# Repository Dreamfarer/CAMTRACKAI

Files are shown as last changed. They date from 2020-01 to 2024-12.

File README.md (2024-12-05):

# CamTrackAI

This is our project work for school. It is an autonomous device powered by a Raspberry Pi 4 that rotates a camera according to object tracker data by OpenCV.

It uses the TCP/IP to send a video source from the Raspberry Pi to a more powerful computer to calculates the object tracking. It will return the calculated data to the Raspberry Pi which then communicates with our Dynamixel Rx-64 motors.

## Prerequisites

You will need these following utilities/devices:

* [Dynamixel Rx-64](http://www.robotis.us/dynamixel-rx-64-hn05-n101/) (x2) - These are the motors we used. But you can use any Robotis Dynamixel motor.
* [Robotis USB2Dynamixel Adapter](https://www.trossenrobotics.com/robotis-bioloid-usb2dynamixel.aspx) - It is used to communicate with the Dynamixel motors.
* [Raspberry Pi Camera Module](https://projects.raspberrypi.org/en/projects/getting-started-with-picamera) - Our camera, the Pi Cam. But any webcam will work fine.
* [Raspberry Pi 4 Model B](https://www.pishop.us/product/raspberry-pi-4-model-b-4gb/) - The computer we used as server. But you can use any computer with any Linux distro.
* [Gens Ace 5000mah 14.8V](https://www.gensace.de/gens-ace-5000mah-14-8v-45c-4s1p-flat-lipo-battery.html) - You will need a 4S1P Battery to power the motors. Additionally add a 3A step down to 5V to power the Raspberry Pi.

You will need the following libraries/packages to compile this code:

* [OpenCV](https://opencv.org/releases/) (Not included, installing instructions further down) - For the tracking algorithm
* [Dynamixel SDK](https://github.com/ROBOTIS-GIT/DynamixelSDK) (Necessary parts included) - For controlling the Dynamxiel motors
* [FLTK](https://www.fltk.org/software.php) (Not included, installing instructions further down) - GUI
* [Avahi-Daemon](https://linux.die.net/man/8/avahi-daemon) (Not included, installing instructions further down) - Used for mDNS to resolve an IP address by a hostname.

## Installing

### OpenCV installation

Follow the tutorial found [here](https://linuxize.com/post/how-to-install-opencv-on-ubuntu-18-04/). There are two ways presented to install OpenCV. Choose the second way found further down.

After you finished the setup, type a final command into the console.

```
$sudo apt-get install libopencv-dev
```

### FLTK (The Fast Light Tool Kit ) installation

Follow these steps to a successful installation of FLTK. The complete tutorial is to be found [here](https://courses.cs.washington.edu/courses/cse557/14au/tools/fltk_install.html)

Firstly, you will need to download FLTK and extract it. Then follow these steps:

```
$./configure
$make
$sudo make install
```

### Dynamixel SDK installation

We need to load the appropriate Dynamixel library. In the server's makefile, search for:

```
dxl_sbc_cpp
```

and change it to the appropriate library found in '/YOUR/PATH/TO/CAMTRACKAI/DynamixelSDK/build'. If you have a x64 system, change the makefile to:

```
dxl_x64_cpp
```

Note that the suffix '.so' and the prefix 'lib' are missing. Also note that you have to install the library. You can do this by the following:

```
$cd /YOUR/PATH/TO/CAMTRACKAI/DynamixelSDK/build/linux64
$make
sudo make install
```
### Avahi Daemon installation

```
$sudo apt-get install avahi-daemon
```

### Change path

Open both makefiles and find this variable:

```
CAMTRACKAI_PATH = /home/theb3arybear/Desktop/CamTrackAI/GitHub/CamTrackAI
```

Change the path to your location.

```
CAMTRACKAI_PATH = /YOUR/PATH/TO/CAMTRACKAI
```

### Change motor ID

Navigate to in CamTrackAIServer.cpp in Server and find these line:

```
#define DXL_ID_1        1
#define DXL_ID_2        2
```

Change the ID of the motors to match yours. 

```
#define DXL_ID          X
```

### Change resolution

Navigate to CamTrackAIClient.cpp in Client and find these lines:

```
#define SCREEN_X        1920
#define SCREEN_Y        1080
```

Change them to match your monitor. You can run 'xdpyinfo | grep dimensions' if you need to know them.

### Networking Setup

Because this application uses mDNS, you can set up your network how would like it to be. The easiest setup would be connecting the server and the client with an ethernet cable. It is important to match the subnet mask and the IP addresses of both computers. To change the IP address and the subnet mask, type the following to the command line (This is an example, you can choose the addresses freely):

```
$sudo ifconfig eth0 192.168.1.1 netmask 255.255.255.0
```

## Compile and Run

Open the console and move to the makefile's location. First:

```
$make
```

Run the following command (on Raspberry Pi) to start the server:

```
$./CamTrackAIServer
```
Then run the next command (on external Computer) to start the client:

```
$./CamTrackAICLient
```

## Further information

To completely remove OpenCV, type the following line into console:

```
$find . -type d -name "*opencv*" -prune -exec rm -rf {} \;
```

## Known Issues (Unsolved)

* There are issues communicating with more than one Dynamixel motor. For unknown reason you cannot talk to two motors shortly after each other. There must be a short pause.
* After some time it may well be that the program stops for unknown reason.

## Authors

* **Dreamfarer** - *Project Planning/Coding/GitHub/Documentation*
* **Kay** - *Project Planning/Planning and building of construction/Documentation*
* **Luca** - *Project Planning/Documentation*

* **Jeremy Morgan** - *Provided code for reading output of a console command (getStdoutFromCommandFunc function in client.cpp)* - [Found Here](https://www.jeremymorgan.com/tutorials/c-programming/how-to-capture-the-output-of-a-linux-command-in-c/)
* **Steve Tuenkam** - *Provided idea behind sending video over TCP/IP using OpenCV* - [Found Here](https://gist.github.com/Tryptich/2a15909e384b582c51b5)

## Thanks to

Linus Torvalds for creating the best kernel, the guys over Parrot OS for the best Linux distro, the whole stackoverflow community for providing ideas and saving programmers' lives.

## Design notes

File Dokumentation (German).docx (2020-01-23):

Eine Projektarbeit von: Luca Gloor G3A, Gianluca Imbiscuso G3A und Kay Obermeier G3A Unter Betreuung von Martin Stangl

22.1.2020

Dokumentation

Zum Bau eines autonomen, objektverfolgenden Bilderkennungs- und Kamerasystems mithilfe einer Künstlichen Intelligenz.

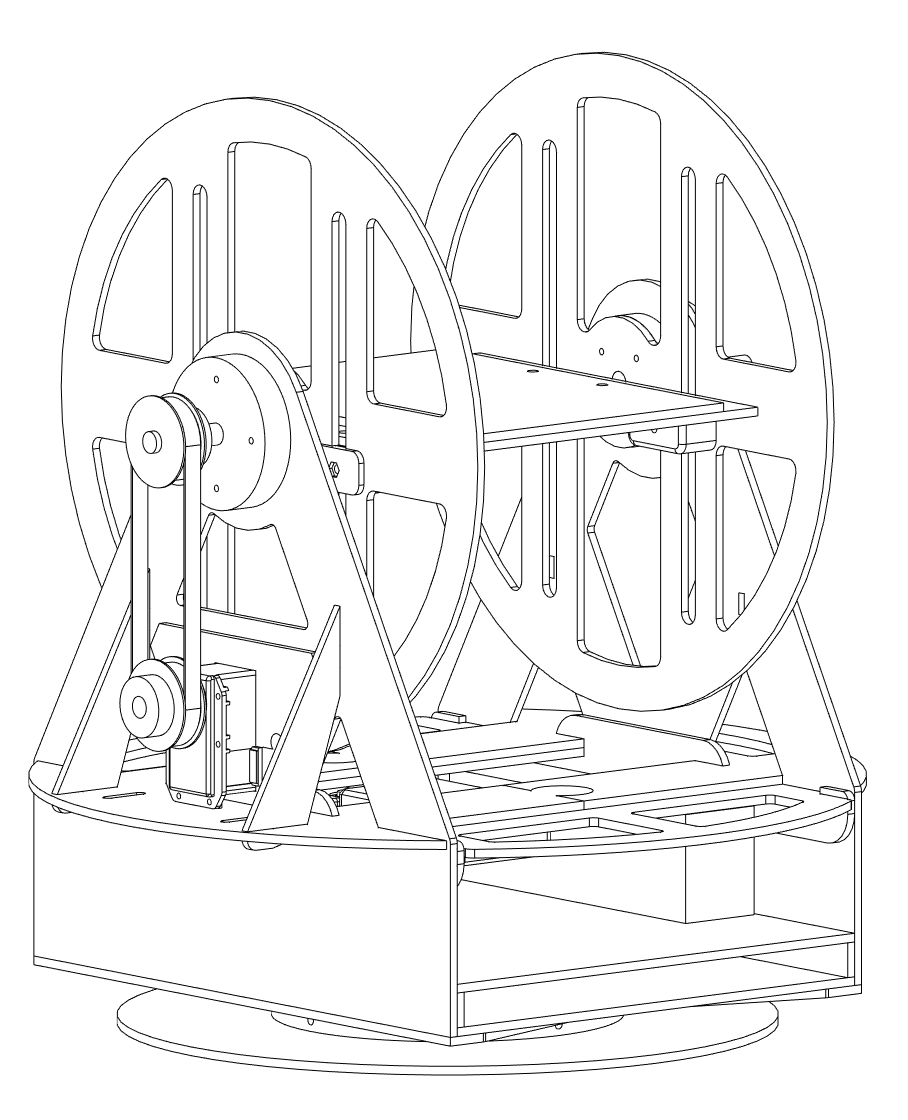
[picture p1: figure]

# Abstract

Diese Projektarbeit befasst sich mit der Entwicklung und der Konstruktion eines autonomen Kamerasystems. Dieses soll in der Lage sein, vom Benutzer ausgewählte Objekte automatisch zu erkennen und zu verfolgen. Das System soll sich in X-, und Z-Richtung drehen können. Gesteuert wird die Konstruktion hierbei mithilfe einer Künstlichen Intelligenz. Um den Aufwand zu verringern, wird die KI eines Open-Source-Projektes verwendet und für unsere Zwecke angepasst.

Die gesamte Arbeit haben wir in einen Konstruktions- und einen Programmier-Teil gegliedert. Das ermöglichte uns, gleichzeitig und unabhängig voneinander bereits an der Konstruktion sowie am Programm zu arbeiten.

Mit unseren Ergebnissen sind wir zufrieden. Natürlich gibt es noch hunderte Dinge, die man an diesem Projekt weiterführen, verfeinern oder neu hinzufügen könnte.

# Vorwort

Wir sind an einer Flugshow auf diese Idee gestossen. Da es sehr anstrengend ist einen gesamten Nachmittag die Kamera zu halten, kamen wir auf die Idee ein Gerät zu bauen. Da zu diesem Zeitpunkt gerade die Projektarbeit bevorstand, entschieden wir uns dieses Projekt zu verwirklichen.

Wir wollen uns hiermit bei allen Personen bedanken, die uns bei der Arbeit unterstützt haben.

Besonderer Dank geht an Andreas Obermeier der für uns den Raspberry Pi, die Pi Cam, die Dynamixel Motoren, die Zahnriemen, Wellen- und Axiallager sowie das Holz zur Verfügung stellte. Auch für die stetige Hilfsbereitschaft für Tipps und Vorschläge sind wir sehr dankbar.

Ebenso danken wir auch unserer Betreuungsperson Martin Stangl für den reibungslosen Start in unser Projekt.

# Inhaltsverzeichnis

# 1. Einleitung

Autonomes Objekttracking ist an sich keine neue Idee. Oftmals werden aber die zu trackenden Objekte speziell markiert, damit ein Gerät diese leicht erkennen kann. Bei unserer Arbeit haben wir eine Künstliche Intelligenz angewendet, die das Objekt anhand seiner Form erkennt und somit die Motoren ansteuern kann. Solche Systeme sind auch heutzutage bereits existent, nur findet man solche Systeme nur in der Rüstungsindustrie. Wir versuchen eine «Low-Budget» Variante in Marke Eigenbau nachzubauen.

## 1.1 Hauptziel

Das Hauptziel der Arbeit ist der Bau eines Drehturmes, welcher eine Kamera um die eigene X-Achse, wie auch die Z-Achse drehen kann. Da dieser autonom angesteuert werden soll, wurde die Verwirklichung des Projektes in 2 Teile aufgeteilt: Die Konstruktion des Drehturmes und die Einbettung der Künstlichen Intelligenz für die Ansteuerung der Motoren, die den Turm bewegen.

## 1.2 Eigene Zusatzkriterien

### Universell brauchbare Plattform für den Gebrauch verschiedener Kameratypen

Das Ziel dieses Kriteriums ist es, dass nicht nur wir, sondern auch andere Menschen mit anderen Kameras das Kamerasystem verwenden können. Auch mit unterschiedlich grossen Objektiven soll der Drehturm nicht aus dem Gleichgewicht gebracht werden.

### Benutzerfreundliche Bedienungsoberfläche (GUI)

Damit das Kamerasystem von anderen Menschen benutzt werden kann, ist wichtig, dass die Bedienung auf den ersten Blick klar erscheint. Der Benutzer soll das Produkt einfach und ohne zu raten bedienen können.

### Sauberer und übersichtlicher Code

Das Projekt soll nicht einfach funktionieren, sondern auch nachvollziehbar sein. Da alles durch ein Programm gesteuert wird, ist das Ziel dieses Kriteriums, dass dessen Code sauber geschrieben, kommentiert und übersichtlich gestaltet ist.

# 2. Theoretische Grundlagen

## 2.2 Künstliche Intelligenz

«Künstliche Intelligenz ist ein Teilgebiet der Informatik, welches sich mit der Automatisierung befasst. Der Begriff ist nicht eindeutig, weil eine genaue Definition fehlt.

Ist ein Computerprogramm intelligent, wenn es jedes Sudoku lösen, oder die besten menschlichen Spieler im Schach schlagen kann? Es stellt sich heraus, dass die AI-Komponente für viele komplizierte Probleme schlicht in besonders schlauen und effizienten algorithmischen Lösungen oder Abschätzungen besteht. Solch klassische Herangehensweisen werden oft mit der Abkürzung GOFAI (good oldfashioned AI) bezeichnet. Sie erfordern, dass der Programmierer, aufgrund seiner Intelligenz, einen Lösungsweg für das gegebenen Problem entwickelt und diesen in Programmcode umsetzt.» (Oinf.ch, Künstliche Intelligenz)

GOFAI ist ja schön und gut, doch wirklich intelligent ist das noch nicht. Immer wichtiger wird daher maschinelles Lernen, bei dem der Mensch keinen Lösungsalgorithmus vorgibt. Es basiert viel mehr auf dem Prinzip von Trial und Error. Vorgegeben werden der KI hierbei nur die Eingabe-Daten, ein neuronales Netz und ein Endergebnis. Das neuronale Netz besteht aus mehreren Schichten von Knoten, die miteinander verbunden sind. Je nach Eingabewert werden die Daten im neuronalen Netz verarbeitet und ausgegeben. Wenn das Endergebnis stimmt, werden, auf Basis dieser Generation, kleine Veränderungen in den Verbindungen gemacht, die den Prozess verfeinern. Ebenso wenn das Endergebnis falsch ist. Dann sind die Anpassungen dementsprechend höher und können in eine ganz andere Richtung gehen. So lernt die KI, wo und wie sie sich verbessern kann. Genauso wie wir immer besser werden, wenn wir etwas viel üben oder repetieren, verbessert sich auch die KI entsprechend der Repetitionen, die es macht. Je länger eine KI trainieren kann, desto besser wird sie.

### OpenCV

OpenCV (Open Computer Vision) ist die wohl bekannteste Open Source Bibliothek mit grösstenteils Algorithmen für Echtzeit-Bildverarbeitung. Sie kann auf allen herkömmlichen Betriebssystemen wie Linux, Windows oder Mac OSX kompiliert und verwendet werden. Geschrieben ist die Bibliothek in C/C++, doch sie unterstützt unter anderem auch Python und Java.

### Tracker Algorithmen

Das Ziel des «Object Trackings» ist es, Objekte über viele Bilder hinweg zu verfolgen. Der Tracker generiert ein Aussehens-Modell des ausgewählten Objekts. Hinzu wird ein Bewegungsmodell kreiert. Dieses misst die Geschwindigkeit und die Richtung über mehrere Bilder hinweg und kann so voraussehen, wo das Objekt sein wird. In diesem Bereich sucht der Tracker dann nach einem Objekt, das dem Aussehens-Modell gleicht. Es wird zwischen «Online» und «Offline» unterschieden. «Online» bedeutet, dass der Tracker ein Aussehens-Modell berechnet, während das Programm läuft. Es passt das Modell den Umständen an. «Offline» bedeutet, dass bevor das Programm gestartet wird, der Tracker schon weiss, wie das Aussehens-Modell aussieht. Solche Tracker werden zum Beispiel genutzt, um Gesichter zu erkennen. Diese Tracker sind viel schneller und in ihrer trainierten Disziplin sehr gut, doch können nur diese spezifischen Objekte verfolgen.

## 2.3 Motoren

### Schrittmotoren

Schrittmotoren sind in der Robotik immer anzutreffende Motoren. Durch ihre Einfachheit und hohen Präzision eignen Sie sich stark für solche Projekte. Auch sind sie sehr preisgünstig und Energieeffizienz. Jedoch haben Schrittmotoren wegen ihrer hohen Präzision im Vergleich zu anderen Motoren ein tiefes Drehmoment.

### Dynamixel Motoren

Dynamixel Motoren sind professionelle Motoren für die Robotik. Sie sind sozusagen die Königsklasse was Motoren betrifft. Durch ihre kompakte Grösse haben sie im Vergleich zu anderen Motoren ein enorm hohes Drehmoment. Ebenfalls lassen sich diese Motoren in Serie schalten, welches die Kabelführung bei Robotern extrem vereinfacht. Durch Ihre hohe Leistung, Qualität und Anwendungsmöglichkeiten fallen solche Motoren oft sehr teuer aus. Speziell bei diesen Motoren ist eine kompliziertere Ansteuerung. Um die Motoren über eine USB-Schnittstelle anzusteuern, braucht man einen Dongle. Für Dynamixel Motoren heisst dieser USB2Dynamixel.

## 2.4 Raspberry Pi

Ein Raspberry Pi ist ein kompakter Computer, nicht viel grösser als ein DIN A7 Papier. Er eignet sich wunderbar als Rechner für selbstgebaute Geräte. Durch seine Einfachheit und Modularität findet man einen Raspberry Pi in allen möglichen Schulprojekten. Ebenfalls ist dieser Computer sehr preisgünstig und vergleichsweise leistungsstark.

## 2.5 FLTK Fast Light Toolkit

FLTK ist eine auf C++ basierende GUI (General User Interface), die auf allen herkömmlichen Betreibsystemen wie Linux, Mac OSX und Windows funktioniert. Sie ist klein, schnell, portabel, benutzerfreundlich und braucht wenige Ressourcen. Das hauseigene Programm FLUID kann benutzt werden, um eine GUI aufzubauen.

## 2.6 Makefile

Ein wichtiger Teil des Kompilierens sind sogenannte Makefiles. Makefiles sind Linux-spezifische Dateien, in denen Parameter für den Kompilierer hineingeschrieben werden. Dies erleichtert das Kompilieren. Man schreibt einfach «$make» in den Terminal und das ganze Projekt wird kompiliert.

## 2.7 TCP/IP

TCP/IP ist eine Protokoll-Familie, welche genutzt wird, um mit anderen Computern über ein Netzwerk zu kommunizieren. Das TCP (Transmission Control Protocol) nimmt Daten von Anwendungen an und teilt sie in Pakete auf. Diese übergibt es dann dem IP (Internet Protocol). Dieses Protokoll sorgt dafür, dass die Pakete vom TCP adressiert und über das Netzwerk gesendet werden.

## 2.8 mDNS

Das Konzept des mDNS (Multicast DNS) löst Hostnamen zu IP Adressen auf und folgt dem herkömmlichen Prinzip des DNS. Dies hat jedoch einen Haken, denn es muss ein DNS Server im Netzwerk aufgesetzt sein. Dies ist nicht oft der Fall. Genau hier setzt mDNS an. Durch mDNS präsentiert sich der Computer im Netzwerk und sendet seine IP Adresse, wenn ein Computer seinen Namen «ruft».

# 3. Methode

## 3.1 Bau des Drehturms

### Konstruktion des Grundgerüsts

Für den Bau des Drehturms haben wir uns entschieden, das gesamte Produkt zuerst in einem CAD-Programm zu entwerfen und zu designen. Wir haben uns hierbei auf Fusion 365 geeinigt. Das CAD-Programm ist für Privatpersonen gratis zu gebrauchen. Da wir bereits in früheren, privaten Projekten dieses CAD benutzten, fiel es uns leicht mit diesem zu arbeiten.

Als Grundidee des Drehturms nahmen wir die Kameradrehtürme aus Drohnen zum Vorbild. Diese bestehen aus zwei motorisierten Achsen, eine für die Höhen- und die andere für die Seitenverstellung. Grob gesehen ist es ein Riesenrad auf einem Karussell.

Am Anfang begrenzten wir uns auf eine Grösse für die Kameras. Im Durchschnitt ist eine Fotokamera etwa 15cm breit. Damit wir genug Spielraum hatten, setzten wir unsere Breite für den Hauptlift auf 20cm. Von da aus konnten wir anfangen. Als Erstes entstand der Hauptlift. Dabei haben wir darauf geachtet, möglichst viele Verstellmöglichkeiten miteinzubauen, um nachher eine Kamera im Schwerpunkt ausbalancieren zu können. Man kann auf der Seite die Höhen-, und von oben die Tiefenlage der Kamera einstellen. Als Nächstes kamen die Stützen. Da die Stützen die grössten Bauteile sind, mussten wir auf unsere Möglichkeiten achten und die Grösse gemäss den möglichen Dimensionen unseres Lasercutters anpassen. Relativ schnell hatten wir dann bereits ein «Riesenrad».

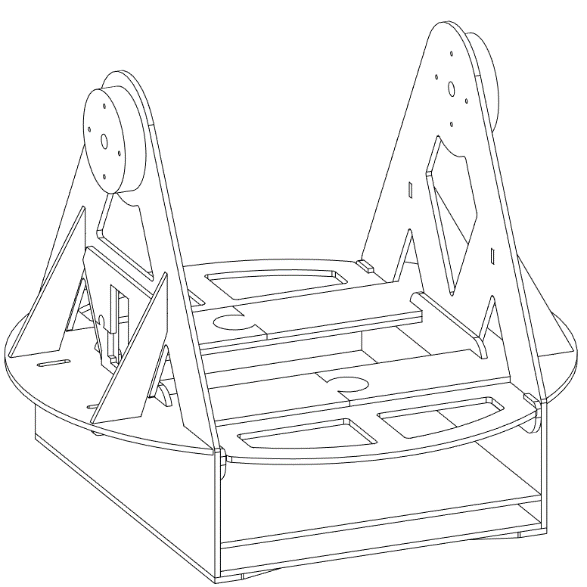
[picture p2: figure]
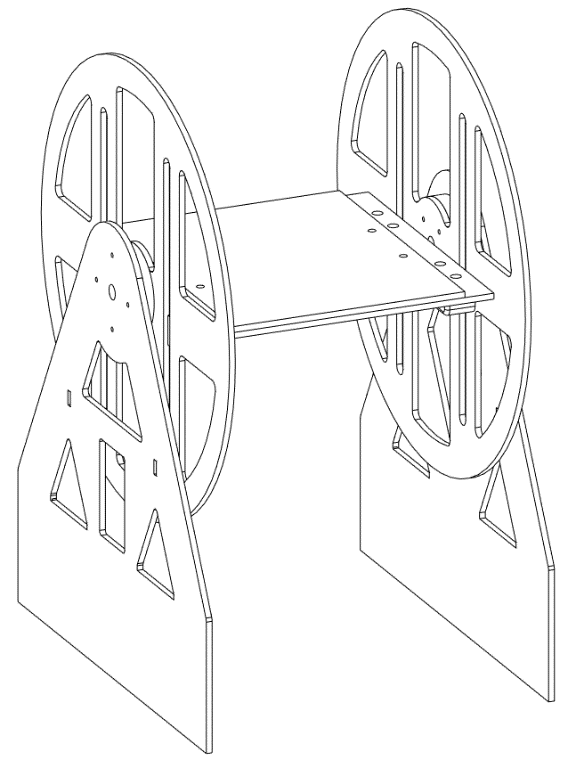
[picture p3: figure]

Um die Kamera auch auf die Seite schwenken zu können, brauchten wir das «Karussell». Dafür mussten wir zuerst eine grundlegende Entscheidung treffen. Ob wir die Elektronik mit dem «Riesenrad» mitdrehen, welches zu einem höheren Kraftaufwand führt, da mehr Masse bewegt wird, oder ob wir nur das «Riesenrad» drehen, ohne der Elektronik, welches zu möglichen Problemen mit verdrehten Kabeln führen könnte. Der Einfachheit wegen entschieden wir uns, die Elektronik mitsamt dem «Riesenrad» zu drehen. Hier fiel das Design recht einfach aus. Durch das Hinzufügen von mehreren Etagen, konnten wir eine praktische Plattform errichten und durch unseren Entscheid, alles mitzudrehen, muss nur ein Kabel der Kamera um eine Achse gedreht werden.

Abbildung 1: Die fertige Konstruktion des «Karussells»

Abbildung 2: Die fertige Konstruktion des «Riesenrads»

Als Nächstes mussten wir uns Gedanken darüber machen, wie wir die entsprechenden Achsen ansteuern und drehen können. Da gewöhnliche Zahnräder ziemlich viel Umkehrspiel haben, fiel die Entscheidung leicht, Zahnriemen zu verwenden. Der Grund: Zahnreimen sind relativ preisgünstig, präzise und erlauben es, Kräfte über weite Strecken mit wenig Platzaufwand zu übertragen. Ein Nachteil, den wir nicht in Betracht gezogen haben, ist, dass es nötig ist die Zahnriemen recht stark zu spannen.

Mit all diesen Voraussetzungen ging es nun darum, die Konstruktion auch umsetzbar zu machen. Wir entschieden uns für vier Millimeter dickes Sperrholz, welches wir mit dem Lasercutter bearbeiten konnten. Man könnte das Sperrholz in Zukunft auch mit stärkeren Aluminiumplatten ersetzen. Hierbei mussten wir uns achten, Verstärkungen dort einzusetzen, wo die Konstruktion zu brechen drohte. Gleichzeitig mussten wir auch schauen, dass wir an stabilen Orten, bei denen eher das Eigengewicht des Teiles zum Problem wurde, kleine Teile ausschneideten, sodass eine gute Balance zwischen Stabilität und Gewicht gefunden werden konnte. Verstärkt wurden vor allem die untere Hälfte, um die oberen Aufbauten halten zu können. Rausgeschnitten wurde vor allem am «Riesenrad», um die aufzuwendende Kraft gering zu halten. Das Ziel war, eine möglichst selbsttragende Konstruktion zu haben, um Klebstellen zu entlasten. Hier haben uns oft mit ineinander gehenden Zungen (Puzzleteilprinzip) geholfen. Mit dem fertigen Entwurf ging es dann an die Produktion.

Innerhalb von einer Woche wurden alle Teile mit dem Lasercutter geschnitten. PLA-Plastikteile, wie Klemmen und Lager-, sowie Motorhalterungen wurden mit dem 3D-Drucker gedruckt. Der Lasercutter schnitt eine Woche lang, durchgehend mit einer Geschwindigkeit von 120mm/min (mit je zwei Durchgängen pro Schnitt), alle Teile aus. Der 3D-Drucker benötigte etwas weniger als 50 Stunden, um alle Bauteile fertig zu stellen.

Damit das Sperrholz stabiler war, wurden alle Teile drei Mal mit Nitro-Hartgrund bestrichen. Durch das Bestreichen wurde das Holz trockener, härter und länger haltbar. Nach dem Auftragen wurden alle Teile nochmals geschliffen.

Für den Zusammenbau wurden Klebungen für Holz-zu-Holz-Verbindungen vorgesehen und für die Plastikteile hauptsächlich Schrauben der Grösse M3. Ausnahmen findet man bei den Motoren, da die standardmässig bereits M2,5 Bohrungen hatten.

### Mechanische Konstruktion

Beide Motoren werden von jeweils einem Motor angetrieben. Da der Motor nicht direkt auf der Achse liegt, mussten wir die Kraft umleiten. Dabei halfen uns die Zahnriemen. Für alle drehende Teile wurden nur, abgesehen von den Zahnriemen aus Glasfaser und Gummi, Aluminiumteile gebraucht. Dazu gehören:

2x 80mm Aluminiumachsen für das «Riesenrad»

4x 40mm Zahnriemenscheiben T5

2x passende Zahnriemen T5

2x Wellenkugellager 26x10x8mm

1x Axialkugellager 76x100x19mm

Natürlich passte nicht alles direkt zusammen. Beinahe alle Teile mussten überarbeitet werden. Die Aluminiumachsen wurden aus einem Stabrohling gedreht. Der Durchmesser musste von circa 10.03mm auf ein leichtes Untermass von 9.98mm gedreht werden, damit die Achse perfekt auf das aufgebohrte Loch der Zahnriemenscheibe und des Wellenkugellagers passte. Die Zahnriemenscheiben für die Motoren und für die Achse mussten auch angepasst werden. Dafür wurden in zwei Zahnriemenscheiben entsprechende Löcher für die Motorenaufnahme gebohrt, in die beiden anderen Zahnriemenscheiben die Löcher der Achsen aufgebohrt und seitlich in einem Loch ein Gewinde hinzugefügt. Für alle drei Kugellager wurde aus PLA-Plastik eine Halterung gedruckt. Alles zusammengebaut bietet uns einen leichten und sauberen Lauf der Achsen.

### Elektrische Strom- und Kabelverwaltung

Für die Motoren mussten noch Kabel gecrimpt werden. Dynamixel verwendet für ihre Motoren standardmässige Molex Stecker. Diese sind im Detailhandel einfach erhältlich. Wir mussten für das zusätzliche Kabel zwischen den beiden Motoren nur die vorgecrimpten Kabel mit den Buchsen zusammenstecken. Für den Anschluss am Akku mussten wir dann die beiden Data-Pins mit einem 120 Ohm Widerstand verbinden und die beiden Stromphasen an den Akku anstecken. Den Akku besassen wir bereit, da er für Flugmodelle gebraucht wurde. Für unser Projekt passt er ebenso gut. Es ist ein 4S 5000mAh Lipo Akku. Da er bereits die nötige Spannung von 14.8V bringt, können wir die Motoren ohne Bedenken direkt anschliessen.

Der Raspberry Pi benötigt auch Strom, aber nicht die direkten 14.8V, sondern 5V. Deshalb haben wir uns einen Spannungswandler gekauft, der konstante 5V mit 3A ausgibt. Diesen haben wir mit den Kabeln der Motorenspeisung zusammen in einen EC5 Stecker für an den Akku gelötet.

## 3.2 Applikationsentwicklung

### Anpassungen an der Künstlichen Intelligenz

Für die Applikationsentwicklung fingen wir zuerst mit der KI an. Wir entschieden uns, OpenCV zu benutzen. Da wir noch nie mit OpenCV arbeiteten, brauchten wir einen Anfang. OpenCV stellt einfache C++ Beispiele auf ihrer Webseite zur Verfügung. Als erster Schritt galt es, jede Variabel und jede Funktion zu verstehen. Dies war der wichtigste Schritt von allen, denn er legte die Basis, um die sehr abstrakte und komplexe OpenCV-Dokumentation verstehen zu können. Das Beispiel konnte lediglich ein Objekt verfolgen und ein Rechteck im Fenster zeichnen, welches den Tracker visualisierte. Beim Aufstarten wurde ein Standbild der Kamera gezeigt, in welchem man daraufhin ein Objekt zum Tracken auswählen konnte. Wir erweiterten das Programm, sodass es Daten in einem zweiten Fenster ausgeben konnte. Diese Daten waren zum Beispiel die Auflösung und das Zentrum des Rechtecks. Wir befassten uns genauer mit dem Tracker und schafften es, den Tracker zu glätten, sodass er nicht mehr herumspringt oder zittert. Diese Massnahme sollte später den Motoren helfen, gleichmässige und ruckelfreie Bewegungen auszuführen.

### Ansteuerung der Motoren

Der nächste grosse Abschnitt des Projekts war es, die Dynamixel-Motoren in unser Programm einzubinden. Wieder bei null anfangend, suchten wir nach Anleitungen und Bespielen. Auf der offiziellen GitHub Seite von Dynamixel wurden wir fündig und schafften es, die Bibliothek zu installieren. Mit dem Paket kamen simple C++ Beispiele. Durch die Dokumentation und mehrere Anleitungen fingen wir an, die Funktionsweise zu verstehen. Leider funktionierte nicht einmal das Beispiel. Wir versuchten, das ganze Beispiel bis auf das Nötigste zu kürzen, doch dies funktionierte ebenfalls nicht. Wir nahmen die Dynamixel-GUI in Windows zur Hilfe, um zu testen, ob die Motoren überhaupt betriebsbereit waren. Das waren sie und uns wurde klar, dass etwas an diesem Code falsch sein musste. Ausserdem wurde uns klar, dass der Motor eine anderen ID besass, als im C++ Beispiel geschrieben war. Doch dies half herzlich wenig. Beim Durchsuchen der Dokumentation wurden wir auf verschiedene Sendefunktionen aufmerksam. Zu den Motoren wird ein Array aus Bytes über den USB2DYNAMIXEL-Adpater gesendet. Beim Ansteuern definiert man, welcher Teil vom Array angesprochen wird. Dieser spezifische Teil wird dann geändert. Es gibt sowohl R (ReadOnly) als auch RW (Read&Write) Werte. Die «ReadOnly» Werte können nur gelesen werden, während die «Read&Write» Werte auch verändert werden können.

Zu jedem Motor muss eine ID definiert werden, um die Motoren untereinander unterscheiden zu können. Die Motoren sind in Serie nacheinander gekoppelt. Dies bedeutet, dass die Signale durch alle Motoren verlaufen, bis sie ihren Zielmotor erreichen.

Eine der Funktionen funktionierte und der Motor drehte sich das erste Mal. Wieso der Motor mit den anderen Sendefunktionen nicht funktionierte, ist unklar. Wahrscheinlich ist der Motor schon zu alt und die Beispiele sind für die neueren Motoren ausgelegt.

Dynamixel Motoren unterstützen generell zwei verschiedene Modi; den Wheel-Mode und den Joint-Mode. Der Joint-Mode ist dabei vorinstalliert. Dieser Modus funktioniert mit Grad. Die Motoren können jedoch nur circa 270° drehen. Eine volle Umdrehung ist also nicht möglich. Der Vorteil ist, dass die Position (Winkel in °) jederzeit abgefragt werden kann. Der Wheel-Mode unterscheidet sich darin, dass er nicht mit einer Position funktioniert, sondern mit einer Geschwindigkeit. Die Motoren können unendlich drehen, doch haben keine Angaben an welchen Positionen sie sich gerade befinden. Gewählt wurde für dieses Projekt der Wheel-Mode, denn der Turm soll sich unendlich drehen können. Hinzu kommt, dass der Tracker von OpenCV die Positionsabfrage übernimmt. Er instruiert die Motoren, sich so lange zu bewegen, bis sich das verfolgte Objekt in der Mitte befindet. Problem hierbei ist, dass wenn ein Motor instruiert wird, sich mit voller Leistung zu drehen, dann tut er dies, bis er einen anderen Wert für die Geschwindigkeit zugesendet bekommt. Bei einem Absturz des Programms dreht er also unendlich, bis der Strom gekappt wird. Auf der X-Achse ist dies kein grosses Problem, doch bei der Z-Achse würde es die RPi IR-CUT Camera mitreissen. Als Sicherheitsmassnahme dafür wurde eingerichtet, dass, falls die Verbindung abgebrochen würde, der Raspberry Pi neu startet und das Programm erneut von selbst ausführt.

Wir veränderten anfänglich nur den Beispiel-Code, um den Dreh rauszukriegen. Das Kompilieren des Codes und das Verändern des Makefiles war und unklar. Es galt also, dies zuerst zu verstehen, bevor wir in der Lage waren, das Beispiel auf unser Programm anzuwenden. Durch Ausprobieren und Recherchieren war dies jedoch schnell gelernt. Wir schafften es, die beiden Projekte zu kombinieren.

Wir programmierten den Code, um die vom Tracker herausgegebenen Werte in Motoreninstruktionen umzuwandeln. Nun war das Programm in der Lage, die Motoren selbst zu steuern.

### Entwerfung der GUI

Ein weiterer Teil der Arbeit enthielt das Kreieren einer GUI (Benutzeroberfläche). FLTK stellte eine geeignete Oberfläche zur Verfügung, welche einfach anzupassen war. So wurde das OpenCV Fenster durch FLTK ersetzt.

Wir starteten auf GitHub ein neues Projekt, um das Transferieren der Files zu erleichtern. Diese sollen für alle zugänglich und reproduzierbar sein.

### Verbindungsprobleme und ihre Lösungen

Da der Raspberry Pi eine andere Architektur besitzt, als der Computer, auf dem alles entwickelt wurde, funktionierte das Programm auf dem Raspberry Pi zuerst nicht. Das Makefile wurde angepasst und nicht vorhandene Bibliotheken wurden installiert. Auf GitHub schrieben wir Anleitungen, wie alles installiert und kompiliert werden muss. Jedoch war es nicht, wie geplant, möglich, alles nur auf dem Raspberry Pi laufen zu lassen, denn nach dem portieren des Programms auf den Raspberry Pi lief der Verfolgungsalgorithmus nur mit zwei Bildern pro Sekunde. So konnte keine Echtzeit-Objekt-Verfolgung erreicht werden. Durch Datenübertragung über ein Netzwerkverbindung wird das Berechnen einem anderen Computer mit mehr Rechenleistung überlassen. So erhöhte sich die Zahl auf elf Bilder pro Sekunde.

Der Raspberry Pi ist mit dieser Lösung für das Steuern der Motoren und für die Übertragung des Bildes verantwortlich. Ein beliebiger anderer Computer empfängt das Bild und berechnet, durch den Verfolgungs-Algorithmus, Werte, die als Bewegungsinstruktionen für die Motoren zurückgeschickt werden.

Da wir in den meisten Netzwerken nicht über den Zugriff auf den Router oder den Switch verfügen, können wir den Computern keine statische IP zuweisen. Da der Raspberry Pi Raspberry Pi an keinem Bildschirm angeschlossen ist, kreiert dies die Herausforderung, die IP des Raspberry Pis herauszufinden. Gelöst wurde dies mit mDNS. So verbindet sich der Computer automatisch mit dem Raspberry Pi.

Unser Programm basiert auf einem «Call-Response» Schema zwischen dem Raspberry Pi und dem Computer. Das heisst, dass der eine Partner Daten schickt, während der andere wartet, bis alles angekommen ist. Danach werden die Positionen gewechselt. Der vorherigen Sender ist nun der Empfänger. Diese Abfolge wiederholt sich, bis einer der Partner die Verbindung abbricht.

Auf GitHub fanden wir ein Projekt, welches in der Lage war, Bilder über das Netzwerk an OpenCV zu senden. So kann der Raspberry Pi Bilder an den Computer senden, welcher die Bilder in Instruktionen für die Motoren umwandelt und diese zurücksendet. Der Raspberry Pi bewegt mit diesen Instruktionen die Motoren.

Somit funktioniert alles. Der Raspberry Pi kann vom Computer aus ausgeschalten oder neu gestartet werden und braucht somit selbst keine Peripheriegeräte.

# 4. Produkt und Applikation

## 4.1 Drehturm

Der Drehturm kommt in zwei Teilen, der Grundplatte und dem Turm. Beide Teile können auseinandergenommen und wieder verschraubt werden. Für den Zusammenbau braucht man einen Schlitz-Schraubenzieher. Die Schrauben zum Anziehen befinden sich im Tiefbau. Um eine Kamera zu montieren, braucht man einen Torx-Schraubenzieher. Die Höhe kann, mithilfe von vier Schrauben, unter dem Hauptlift eingestellt werden. Die Tiefe kann, von oben, ebenfalls mit vier Schrauben verstellt werden. Nach längerem Gebrauch sollte das Axiallager wieder mit normalem Schmieröl geölt werden.

## 4.2 Programm

Die Ansteuerung ist ebenfalls zweiteilig aufgebaut. Zum einen muss der Raspberry Pi und zum anderen ein externer Rechner gestartet werden. Hierbei muss darauf geachtet werden, dass der Raspberry Pi zuerst läuft. Das Programm wird auf dem externen Rechner gestartet und verbindet sich, per Ethernet, automatisch mit dem Raspberry Pi. Der Nutzer wird daraufhin aufgefordert, einen beliebigen Tracking Algorithmus zu wählen. Der letzte Schritt beinhaltet das Auswählen des Objekts mit der Maus. Daraufhin bewegt sich der Turm und verfolgt das zuvor gewählte Objekt. Dies ist so lange der Fall, bis der Nutzer das Programm schliesst, oder den Tracker stoppt und ein neues Objekt auswählt.

# 5 Ergebnisse und Schlussfolgerungen

## 5.1 Konstruktion

Der Drehturm ist insgesamt sehr robust herausgekommen. Die Schnittqualität der einzelnen Teile hat uns sehr überrascht. Im Grossen und Ganzen funktionierte der Zusammenbau einwandfrei. Die Teile passten ohne jegliche Nachbearbeitung. Auch die Bewegung verlief während dem Testen sehr flüssig. Während dem letzten Test verklemmte sich die Konstruktion und wir konnten sie nicht mehr drehen. Der Grund dazu ist uns unbekannt. Weitere Mängel mussten wir an der Z-Achse feststellen. Bei dieser fiel durch das leichte Gesamtgewicht der Turm oft aus dem Axiallager. Ebenso haben wir zu kleine Toleranzen für das Spannen der Zahnriemen mit einberechnet. Hier hätten ein paar Millimeter mehr geholfen. Insgesamt waren wir durch die hohe Stabilität des Sperrholzes sehr beeindruckt.

## 5.2 Software

Der Code an sich ist für uns überraschend kurz ausgefallen. Ebenso hat uns die Schnelligkeit und Präzision des Trackers beeindruckt. Was uns noch nicht gelungen ist, ist während des Betriebes auf verschiedene Tracker-Algorithmen umzusteigen, sprich, zwischen den Menüs zu wechseln. Ebenso hängt sich der Raspberry Pi in vereinzelten Fällen auf und die Motoren drehen unkontrolliert weiter. Dafür haben wir bis dato keine Lösung gefunden. Hingegen konnten wir bei Kommunikationsproblemen auf der Seite des externen Rechners ein unkontrolliertes Durchdrehen der Motoren verhindern, indem der Raspberry Pi von selbst neustartet.

# 6. Zusammenfassung

## 6.1 Selbstreflektion

Wir haben dank diesem Projekt unseren Horizont sehr erweitern können. Uns war am Anfang nicht bewusst, was auf uns zukommt und wie wir unsere Vision in Wirklichkeit umsetzten können. Die Konstruktion konnten wir selbständig konzipieren und ausarbeiten, da wir bereits Vorkenntnisse im Gebrauch von CAD-Programmen hatten. Dank unseren Vorkenntnissen im Programmieren konnten wir OpenCV mithilfe von kleinen Beispielen erlernen. Stein um Stein fingen wir an, das Programm zu erweitern. Der nächste grosse Schritt war, die Dynamixel Motoren einzubinden. Dies gelang uns auch, obwohl wir anfängliche Schwierigkeiten hatten. Viel Ausprobieren, Hinfallen und wieder Aufstehen war gefragt. Uns wurde bewusst, wie schwer es sein kann, ein Programm mit Technik zu verbinden. Wir sind sehr stolz auf das, was wir erreicht haben, doch wir sehen auch ein, dass noch viel Potential vorhanden ist. Dass es am Ende doch nicht ganz funktioniert hat, ist natürlich enttäuschend.

## 6.2 Gesamtprodukt

In Theorie hätte alles natürlich funktionieren können. Das Programm kann auch weiter genutzt werden. Dass am Ende nur wegen zu hoher Reibung die Z-Achse nicht funktionstüchtig war, ist sehr schade.

# 7. Quellenverzeichnis

Dokumentation Open CV: https://docs.opencv.org/4.2.0/

Abgefragt am 14.9.2019 21:37

Tutorial zum gebrauch von Verschiedenen Trackern:https://www.learnopencv.com/object-tracking-using-opencv-cpp-python/

Abgefragt am 15.9.2019 17:04

FLTK Programm: https://www.fltk.org/index.php

Abgefragt am 8.11.2019 20:16

FLTK Dokumentation: https://www.fltk.org/documentation.php

Abgefragt am 8.11.2019 20:53

E-Manual für Dynamixel Motoren: http://emanual.robotis.com/docs/en/dxl/rx/rx-64/

Abgefragt am 10.10.2019 19:35

Jeremy Morgan - Provided code for reading output of a console command (getStdoutFromCommandFunc function in client.cpp): https://www.jeremymorgan.com/tutorials/c-programming/how-to-capture-the-output-of-a-linux-command-in-c/

Abgefragt am 21.11.2019 20:32

Grundlage der Makefiles: https://github.com/ROBOTIS-GIT/DynamixelSDK/tree/master/c%2B%2B/example/protocol1.0/read_write/linux64

Abgefragt am 13.12.2019 19:23

Steve Tuenkam - Provided idea behind sending video over TCP/IP using OpenCV: https://gist.github.com/Tryptich/2a15909e384b582c51b5

Abgefragt am 11.1.2020 18:14

Recherche für den Theorieteil über Künstliche Intelligenz: https://oinf.ch/kurs/informationsgesellschaft/kuenstliche-intelligenz/

Abgefragt am 22.1.2020 18:21

# 8. Anhang

## 8.1 Source Code

### C++ Source Code Server

### C++ Source Code Client

### Makefile Server

### Makefile Client

## 8.2 Programm

Das Programm ist aufrufbar unter: https://github.com/BE3dARt/CamTrackAI?files=1

5. Ergebnisse und Schlussfolgerungen

Ergebnisse und Schlussfolgerungen

2. Theoretische Grundlagen

Theoretische Grundlagen

4. Produkt und Applikation

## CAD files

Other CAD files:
3D Files/PA_Drehturm.f3d

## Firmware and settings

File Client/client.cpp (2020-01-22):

////////////////////////////////////////////////////////////////////////////////////////////////////
// **CAMTRACKAI**
//
// Coded by BE3dARt (Gianluca Imbiscuso) with <3
//
// Visit https://github.com/BE3dARt/CamTrackAI for the documentation/ installing instructions
////////////////////////////////////////////////////////////////////////////////////////////////////

////////////////////////////////////////////////////////////////////////////////////////////////////
//Include header files
////////////////////////////////////////////////////////////////////////////////////////////////////
#include <iostream>
#include <string>
#include <ctime>
#include <ratio>
#include <chrono>
#include <stdlib.h>
#include <stdio.h>
#include <cmath>
#include <unistd.h>
#include <fcntl.h>
#include <termios.h>
#include <pthread.h>
#include <string>
#include <thread>

#include <FL/Fl.H>
#include <FL/Fl_Box.H>
#include <FL/Fl_Window.H>
#include <FL/Fl_Group.H>
#include <FL/Fl_Wizard.H>
#include <FL/Fl_Button.H>
#include <FL/Fl_Multiline_Output.H>
#include <FL/fl_ask.H>

#include <opencv2/opencv.hpp>
#include <opencv2/tracking/tracker.hpp>
#include <opencv2/highgui.hpp>
#include <opencv2/core/core.hpp>
#include <opencv2/imgproc.hpp>
#include <opencv2/imgcodecs.hpp>

#include <sys/socket.h>
#include <arpa/inet.h>
#include <sys/ioctl.h>
#include <net/if.h>

////////////////////////////////////////////////////////////////////////////////////////////////////
//Defining namespaces
////////////////////////////////////////////////////////////////////////////////////////////////////
using namespace std;
using namespace cv;
using namespace std::chrono;

////////////////////////////////////////////////////////////////////////////////////////////////////
//Define colors for GUI
////////////////////////////////////////////////////////////////////////////////////////////////////
Scalar colorGreen = Scalar(179, 239, 194); //Green
Scalar colorBlue = Scalar(177, 171, 151); //Blue
Scalar colorPurple = Scalar(114, 111, 116); //Purple

////////////////////////////////////////////////////////////////////////////////////////////////////
//Global Variables & Definitions
////////////////////////////////////////////////////////////////////////////////////////////////////
string chosenTracker = ""; //Which tracker to use

//FLTK windows
Fl_Window *firstWindow = 0;
Fl_Window *secondWindow = 0;

//Shutdown and reboot
bool shutDownActivated = false;
bool rebootActivated = false;

//Mouse events
bool mouseClicked = false;
Point leftButtonDown = Point(0, 0);
Point leftButtonHold = Point(0, 0);

////////////////////////////////////////////////////////////////////////////////////////////////////
//Defining Properties
////////////////////////////////////////////////////////////////////////////////////////////////////
#define SCREEN_X                  1920 //X-coordinate of screen (Used for GUI)
#define SCREEN_Y                  1080 //Y-coordinate of screen (Used for GUI)
#define SMALLER_STEP_RATIO				8 //Make motor speed smaller (Required because of problem with overturing of motors combined with input lag)

#define PORT                      4097 //Network port for communication with server (Raspberry Pi)
#define SHUTDOWN						      3001 //Shut down instruction for server (Raspberry Pi)
#define REBOOT							      3002 //Reboot instruction for server (Raspberry Pi)

#define KEY_START           			113	//'q' key
#define KEY_END             			119 //'w' key
#define KEY_REBOOT          			114 //'r' key
#define KEY_SHUTDOWN        			102 //'f' key

////////////////////////////////////////////////////////////////////////////////////////////////////
// callBackFunc function: It triggers when mouse movements or clicks are detected (Used for selecting the Region of interest [ROI])
// @event       Defines for which mouse event the function does what
// @x           x-coordinate of mouse
// @y           y-coordinate of mouse
// @flags       Set additional condition for mouse event (Shift key or Ctrl pressed)
// @user_data   Has to be included by default. No use for this application.
// -->          https://docs.opencv.org/2.4/modules/highgui/doc/user_interface.html?highlight=setmousecallback
////////////////////////////////////////////////////////////////////////////////////////////////////
void callBackFunc(int event, int x, int y, int flags, void * userData) {
  //Triggers when left mouse button is pressed
  if (event == EVENT_LBUTTONDOWN && mouseClicked == false) {
    leftButtonDown = Point(x, y);
    mouseClicked = true;
  }

  //Triggers when mouse moves but only if previously left mouse button was pressed (Now holding)
  if (event == EVENT_MOUSEMOVE && mouseClicked == true) {
    leftButtonHold = Point(x, y);
  }

  //Triggers when left mouse button is released
  if (event == EVENT_LBUTTONUP) {
    mouseClicked = false;
  }

  //Triggers when mouse moves but also shift is pressed
  if (event == EVENT_MOUSEMOVE && flags == EVENT_FLAG_SHIFTKEY) {
    int tempLeftButtonDownX = leftButtonDown.x - x;
    int tempLeftButtonDownY = leftButtonDown.y - y;
    int tempLeftButtonHoldX = leftButtonHold.x - tempLeftButtonDownX;
    int tempLeftButtonHoldY = leftButtonHold.y - tempLeftButtonDownY;

    leftButtonDown = Point(x, y);
    leftButtonHold = Point(tempLeftButtonHoldX, tempLeftButtonHoldY);
  }

  //Triggers when mouse moves but also ctrl is pressed
  if (event == EVENT_MOUSEMOVE && flags == EVENT_FLAG_CTRLKEY) {
    int tempLeftButtonDownX = leftButtonDown.x - x;
    int tempLeftButtonDownY = leftButtonDown.y - y;
    int tempLeftButtonHoldX = leftButtonHold.x + tempLeftButtonDownX;
    int tempLeftButtonHoldY = leftButtonHold.y + tempLeftButtonDownY;

    leftButtonDown = Point(x, y);
    leftButtonHold = Point(tempLeftButtonHoldX, tempLeftButtonHoldY);
  }
}

////////////////////////////////////////////////////////////////////////////////////////////////////
// smoothFrameFunc Function: Used to calculate a smoothed rectangle (So camera will not start to wiggle)
// @frame     	Image (Window) on which to draw the recatngle
// @point_1		Newest tracker center point
// @point_2		-
// @point_3		-
// @point_4		-
// @point_5		Oldest tracker center point
////////////////////////////////////////////////////////////////////////////////////////////////////
Point smoothFrameFunc(Mat frame, Point point_1, Point point_2, Point point_3, Point point_4, Point point_5) {
  double tempX;
  double tempY;
  Point returnValue;

  //Calculate the weighted mean
  tempX = ((point_1.x * 0.4) + (point_2.x * 0.3) + (point_3.x * 0.2) + (point_4.x * 0.05) + (point_5.x * 0.05));
  tempY = ((point_1.y * 0.4) + (point_2.y * 0.3) + (point_3.y * 0.2) + (point_4.y * 0.05) + (point_5.y * 0.05));

  //Make Point to return
  returnValue = Point((tempX), (tempY));

  //Draw Rectangle (smooth follow)
  rectangle(frame, Point((tempX - 50), (tempY - 50)), Point((tempX + 50), (tempY + 50)), colorGreen, 2, 8, 0);

  return returnValue;
}

////////////////////////////////////////////////////////////////////////////////////////////////////
// guiHandlerFunc Function: Updates all GUI values
// @center_X			Pointer to GUI element which displays the tracker's center x value
// @center_Y			Pointer to GUI element which displays the tracker's center y value
// @framesPerSecond		Pointer to GUI element which displays the fps
// @msecondsPerSecond	Pointer to GUI element which displays the milliseconds used for calculating one frame
// @screenSize_X		Pointer to GUI element which displays the image's x size
// @screenSize_Y        Pointer to GUI element which displays the image's y size
// @middle              Point (x,y) of the tracker's center
// @frameInfo           Point (x,y) of the size of the image
// @pictureTime         Time consumed for one while loop, aka calulating one frame
// @smoothedCenter      Point (x,y) of the tracker's smoothed out center
// @errorDisplay        Pointer to GUI element which displays if there is an error with the tracker
// @trackerError        True if there is an error with the tracker
////////////////////////////////////////////////////////////////////////////////////////////////////
void guiHandlerFunc(Fl_Output*center_X, Fl_Output*center_Y, Fl_Output*framesPerSecond, Fl_Output*msecondsPerSecond, Fl_Output*screenSize_X, Fl_Output*screenSize_Y, Point middle, Point frameInfo, double pictureTime, Point smoothedCenter, Fl_Output *errorDisplay, bool trackerError) {
  int fps = 1000/pictureTime;  //Frames per second for calculation

  //What to display if there is an error with the tracker
  string errorString;
  if(trackerError) {
    errorString = "SUCCESS";
  } else {
    errorString = "ERROR";
  }

  //Write values to GUI elements
  center_X->value(to_string(smoothedCenter.x).c_str());
  center_Y->value(to_string(smoothedCenter.y).c_str());
  framesPerSecond->value(to_string(fps).c_str());
  msecondsPerSecond->value(to_string(pictureTime).c_str());
  screenSize_X->value(to_string(frameInfo.x).c_str());
  screenSize_Y->value(to_string(frameInfo.y).c_str());
  errorDisplay->value(errorString.c_str());
}

////////////////////////////////////////////////////////////////////////////////////////////////////
// shutDownFunc Function: Used to shot down or reboot server (Raspberry Pi)
// @socket		The network socket that will be closed
////////////////////////////////////////////////////////////////////////////////////////////////////
void shutDownFunc(int socket) {
  int movementInstruction[2];

  if (rebootActivated) {
    movementInstruction[0] = REBOOT;
    cout << "\n\n=====================================================================================\nRebooting Raspberry Pi ...\n=====================================================================================\n\n" << endl;
  } else {
    movementInstruction[0] = SHUTDOWN; //Set movement instruction to 'REBOOT'. So the Raspberry Pi will receive it and reboot.
    cout << "\n\n=====================================================================================\nShutting down Raspberry Pi ...\n=====================================================================================\n\n" << endl;
  }
  movementInstruction[1] = 0; //Set the motor to 0 movement

  send(socket, movementInstruction , 8, 0); //Send movement instruction to Raspberry Pi

  close(socket); //Close socket

  exit(0); //Exit application
}

////////////////////////////////////////////////////////////////////////////////////////////////////
// trackerMainFunc: Basically the main function. Everything will be called, calculated and executed from here.
// @center_X		 	Pointer to GUI element which displays the tracker's center x value
// @center_Y			Pointer to GUI element which displays the tracker's center y value
// @framesPerSecond		Pointer to GUI element which displays the fps
// @msecondsPerSecond	Pointer to GUI element which displays the milliseconds used for calculating one frame
// @screenSize_X        Pointer to GUI element which displays the image's x size
// @screenSize_Y        Pointer to GUI element which displays the image's y size
// @trackerDisplay		Pointer to GUI element which displays which tracker is used
// @serverIP            Pointer to IP Address
// @errorDisplay        Pointer to GUI element which displays if there is an error with the tracker
////////////////////////////////////////////////////////////////////////////////////////////////////
int trackerMainFunc(Fl_Output*center_X, Fl_Output*center_Y, Fl_Output*framesPerSecond, Fl_Output*msecondsPerSecond, Fl_Output*screenSize_X, Fl_Output*screenSize_Y, Fl_Output*errorDisplay, const char* serverIP) {

  Point smoothedCenter; //Point (x,y) to store the smoothed out center of tracker
  int moveMotorX; //How fast to move motors in x direction
  int moveMotorY; //How fast to move motors in y direction
  int stepX; //How big the steps are for motor movement in x direction (that it is 0 movement in the center and 100% movement at border of screen)
  int stepY; //How big the steps are for motor movement in y direction (that it is 0 movement in the center and 100% movement at border of screen)
  int differnceToCenterX; //Difference from tracker's x center to screen's x center
  int differnceToCenterY; //Difference from tracker's y center to screen's y center
  int positionArray[2] = {0, 0}; //Holds motors movement x and y value (Used for sending over TCP)
  int localSocket; //Socket
  int serverPort = PORT; //Port over which connection goes

  bool running = true; //For exiting the while loop which tracks the object

  duration<double, milli> time_span; //Timeintervall to calculate 'msecondsPerSecond' and 'fps'
  high_resolution_clock::time_point beginTime = high_resolution_clock::now(); //Start of counter
  high_resolution_clock::time_point endTime = high_resolution_clock::now(); //Start of counter

  Point point_1 = Point(1, 9); //Oldest frame
  Point point_2 = Point(2, 8); //-
  Point point_3 = Point(3, 7); //-
  Point point_4 = Point(4, 6); //-
  Point point_5 = Point(5, 5); //-
  Point middle = Point(1,1); //Newest frame
  Point frameInfo = Point(480, 300); //Point (x,y) which holds image resolution

  struct sockaddr_in serverAddr; //Struct that holds IP Adress/Port/Family
  socklen_t addrLen = sizeof(struct sockaddr_in); //Calculate size which is reserved for 'serverAddr'

  Mat img; //holds image (frame)
  img = Mat::zeros(300 , 480, CV_8UC3); //Fill in image (frame) with 0
  int imgSize = img.total() * img.elemSize(); //Image (frame) size
  uchar *iptr = img.data; //Pointer to image (frame) for it to be used with TCP/IP

  namedWindow("CamTrackAI", WINDOW_NORMAL); //Create an OpenCV window

  setMouseCallback("CamTrackAI", callBackFunc, NULL); //Set a callback function for mouse events

  Rect2d trackingBox = Rect2d(Point(100,100), Point(0,0)); //Box which is drawn by the user for selecting the ROI (Region of interest)
  int exitWhile = 0; //Exit a while loop

  bool trackerError; //Returning value by tracker->update()

  //Initiate Socket
  if ((localSocket = socket(PF_INET, SOCK_STREAM, 0)) < 0) {
    cout << "socket()\tERROR!" << endl;
  }

  //Fill in struct 'serverAddr'
  serverAddr.sin_family = PF_INET; //Family
  serverAddr.sin_addr.s_addr = inet_addr(serverIP); //IP Address
  serverAddr.sin_port = htons(serverPort); //Port

  //Connect to socket
  if (connect(localSocket, (sockaddr*)&serverAddr, addrLen) < 0) {
    cout << "connect()\tERROR!" << endl;
    exit(0);
  }

  while (true) {
    //Fill with 0 so that motors won't move
    positionArray[0] = 0;
    positionArray[1] = 0;

    //Evaluate decision by user and define type of tracker to be used. If there was an error, Reboot instructions will be sent to the server (Raspberry Pi).
    Ptr<Tracker> tracker;
    if (chosenTracker == "KCF") {
      tracker = TrackerKCF::create();
    } else if (chosenTracker == "CSRT") {
      tracker = TrackerCSRT::create();
    } else if (chosenTracker == "TLD") {
      tracker = TrackerTLD::create();
    } else if (chosenTracker == "MIL") {
      tracker = TrackerMIL::create();
    } else if (chosenTracker == "MOSSE") {
      tracker = TrackerMOSSE::create();
    } else if (chosenTracker == "Boosting") {
      tracker = TrackerBoosting::create();
    } else if (chosenTracker == "MedianFlow") {
      tracker = TrackerMedianFlow::create();
    } else {
      rebootActivated = true;
      shutDownFunc(localSocket);
    }

    //Choose what object to track (ROI).
    while (exitWhile != KEY_START) {
      recv(localSocket, iptr, imgSize , MSG_WAITALL); //Receive image from server (Raspberry Pi) and store it into 'img' (iptr)

      trackingBox = Rect2d(leftButtonDown, leftButtonHold); //Update rectangle which is drawn with the user's mouse
      rectangle(img, trackingBox, colorPurple, 2, 8); //Make the drawn box visible

      imshow("CamTrackAI", img); //Show image with 'img' and the rectangle in it

      exitWhile = waitKey(20); //Wait 25 milliseconds for a key to be pressed. 'exitWhile' will change to 'KEY_START' if this buttons has been pressed, thus exiting the loop.

      if (exitWhile == KEY_REBOOT) {
        rebootActivated = true;
      }

      if (exitWhile == KEY_SHUTDOWN) {
        shutDownActivated = true;
      }

      //Check if user requested a reboot or shut down of server (Raspberry Pi). Else just send movement instructions to server.
      if (shutDownActivated == true || rebootActivated == true) {
        exitWhile = KEY_START;
        shutDownFunc(localSocket);
      } else {
        send(localSocket, positionArray , 8, 0); //Send movement instructions to motors
      }
    }

    exitWhile = 0; //Reset for it to be used in another loop

    tracker->init(img, trackingBox); //Initalize tracker with the user's defined box

    running = true; //Reset for it to be used in another loop

    while (running) {

      beginTime = high_resolution_clock::now(); //Begin timer

      //Receive image from server (Raspberry Pi) and store it into 'img' (iptr). If there was an error, send reboot instruction to server (Raspberry Pi) and close the application
      if (recv(localSocket, iptr, imgSize , MSG_WAITALL) == -1) {
        cout << "recv()\tERROR!" << endl;
        rebootActivated = true;
        shutDownFunc(localSocket);
      }

      //The tracker searches for the object in the current frame. If it fails, it will send 0 (motor zero movement) to the server (Raspberry Pi) until the object is found again.
      if ((trackerError = tracker->update(img, trackingBox)) == true) {
        rectangle(img, trackingBox, colorPurple, 2, 8); //Make trackerdata visible through a rectangle

        middle = Point((trackingBox.x + trackingBox.width / 2),(trackingBox.y + trackingBox.height / 2)); //Calucalte center of tracker

        //Update Points (from oldest frame to newest frame)
        point_5 = point_4;
        point_4 = point_3;
        point_3 = point_2;
        point_2 = point_1;
        point_1 = middle;

        smoothedCenter = smoothFrameFunc(img, point_1, point_2, point_3, point_4, point_5);

        Fl::check(); //Refresh GUI

        imshow("CamTrackAI", img); //Show image (frame) with the rectangle (tracker data) in it

        //Calculate the steps based on the image's resolution and maximal movement by the Dynamixel motors.
        stepX = 1023 / (frameInfo.x/2);
        stepY = 1023 / (frameInfo.y/2);

        //Calucalte difference from tracker's x center to screen's x center
        differnceToCenterX = smoothedCenter.x - (frameInfo.x/2);
        differnceToCenterY = smoothedCenter.y - (frameInfo.y/2);

        //Checks if the difference from the center is + or minus 0. If it is < 0, it will send a number ranging from 0-1023 to server (Raspberry Pi). If it is > 0, it will send numbers ranging from 1024-2047. This is used to define the direction of spinning.
        if(differnceToCenterX < 0) {
          moveMotorX = (abs(differnceToCenterX) * stepX)/4;
        } else {
          moveMotorX = ((abs(differnceToCenterX) * stepX)/4) + 1024;
        }

        if(differnceToCenterY < 0) {
          moveMotorY = (abs(differnceToCenterY) * stepY)/SMALLER_STEP_RATIO;
        } else {
          moveMotorY = ((abs(differnceToCenterY) * stepY)/SMALLER_STEP_RATIO) + 1024;
        }

        //Set movement instruction for the motors
        positionArray[0] = moveMotorX;
        positionArray[1] = moveMotorY;
      } else {
        positionArray[0] = 0;
        positionArray[1] = 0;
      }

      int k = waitKey(1); //Wait 1 millisecond for key to be pressed (Else it would not detect key pressed)

      // Exit the loop if 'KEY_END' was pressed
      if(k == KEY_END)
      {
        running = false;
      }

      if (k == KEY_REBOOT) {
        rebootActivated = true;
      }

      if (k == KEY_SHUTDOWN) {
        shutDownActivated = true;
      }

      guiHandlerFunc(center_X, center_Y, framesPerSecond, msecondsPerSecond, screenSize_X, screenSize_Y, middle, frameInfo, time_span.count(), smoothedCenter, errorDisplay, trackerError); //Send values to GUI

      //Check if user requested a reboot or shut down of server (Raspberry Pi). Else just send movement instructions to server.
      if (shutDownActivated == true || rebootActivated == true) {
        shutDownFunc(localSocket);
      } else {
        send(localSocket, positionArray , 8, 0);
      }

      //Timestamp 2 and time span calulating
      endTime = high_resolution_clock::now();
      time_span = endTime - beginTime;
    }
  }
  close(localSocket); //Close socket

  exit(0); //Exit application

  return 0;

}

////////////////////////////////////////////////////////////////////////////////////////////////////
// Buttons for the GUI
// @FL_Widget	  Target widget
// @*			  Data that can be stored in a Widget with fltk::Widget::user_data(void*)
// --> 			  Description taken from https://www.fltk.org/doc-2.0/html/group__example2.html
////////////////////////////////////////////////////////////////////////////////////////////////////
//Choose KCF
void b_KCF(Fl_Widget *, void *) {
  fl_beep();
  chosenTracker = "KCF";
  firstWindow->hide();
}

//Choose CSRT
void b_CSRT(Fl_Widget *, void *) {
  fl_beep();
  chosenTracker = "CSRT";
  firstWindow->hide();
}

//Choose TLD
void b_TLD(Fl_Widget *, void *) {
  fl_beep();
  chosenTracker = "TLD";
  firstWindow->hide();
}

//Choose MIL
void b_MIL(Fl_Widget *, void *) {
  fl_beep();
  chosenTracker = "MIL";
  firstWindow->hide();
}

//Choose MOSSE
void b_MOSSE(Fl_Widget *, void *) {
  fl_beep();
  chosenTracker = "MOSSE";
  firstWindow->hide();
}
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
int main(int argc, char **argv) {

  //Resolve IP-address to hostname and store it a string
  string ls = getStdoutFromCommandFunc("avahi-resolve -n raspberrypi.local -4 | grep \"raspberrypi.local\" | cut -f2");
  const char *serverIP = ls.c_str();

  firstWindowFunc(argc,argv); //Show first GUI window

  secondWindowFunc(argc,argv, serverIP); //Show second GUI window
}

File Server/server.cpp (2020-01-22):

////////////////////////////////////////////////////////////////////////////////////////////////////
// **CAMTRACKAI**
//
// Coded by BE3dARt (Gianluca Imbiscuso) with <3
//
// Visit https://github.com/BE3dARt/CamTrackAI for the documentation/ installing instructions
////////////////////////////////////////////////////////////////////////////////////////////////////

////////////////////////////////////////////////////////////////////////////////////////////////////
//Include header files
////////////////////////////////////////////////////////////////////////////////////////////////////
#include "opencv2/opencv.hpp"
#include <iostream>
#include <sys/socket.h>
#include <arpa/inet.h>
#include <sys/ioctl.h>
#include <net/if.h>
#include <unistd.h>
#include <string.h>

#include "dynamixel_sdk.h"

////////////////////////////////////////////////////////////////////////////////////////////////////
//Defining namespaces
////////////////////////////////////////////////////////////////////////////////////////////////////
using namespace cv;
using namespace std;

////////////////////////////////////////////////////////////////////////////////////////////////////
//Defining Properties
////////////////////////////////////////////////////////////////////////////////////////////////////
//Dynamixel
//--Byte positions in array (May differ from motor to motor)
#define CW_ANGLE_LIMIT                  6
#define CCW_ANGLE_LIMIT                 8
#define MOVING_SPEED                    32
#define TORQUE                          24
#define TORQUE_LIMIT                    34

//--Values
#define PROTOCOL_VERSION                1.0
#define BAUDRATE                        57600
#define DEVICENAME                      "/dev/ttyUSB0"
#define DXL_ID_1                        2 //ID of first motor
#define DXL_ID_2                        1 //ID of second motor

//OpenCV
#define VIDEOSOURCE						0
#define RESOLUTIONHEIGHT				300
#define RESOLUTIONWIDTH					480

//Networking
#define PORT                            4097
#define SHUTDOWN						3001
#define REBOOT							3002

////////////////////////////////////////////////////////////////////////////////////////////////////
// shutDownFunc Function: When called shuts down or reboots server (Raspberry Pi)
// @argument			Determines if function shuts down or reboots server (Raspberry Pi)
// @portHandler			Pointer to the porthandler of Dynamixel (Used for port handling)
// @packetHandler		Pointer to the packethandler of Dynamixel (Used for protocol version handling)
// @localSocket			Variable used to modify the local socket
// @remoteSocket		Variable used to modify the remote socket
////////////////////////////////////////////////////////////////////////////////////////////////////
void shutDownFunc(int argument, dynamixel::PortHandler *portHandler, dynamixel::PacketHandler *packetHandler, int localSocket, int remoteSocket) {

	close(localSocket); //Close local socket
	close(remoteSocket); //Close remote socket

	//Set movement of both motors to zero (There needs to be a short break in between the calls because of the adapters speed)
	packetHandler->write2ByteTxOnly(portHandler, DXL_ID_1, MOVING_SPEED, 0);
	cout << "2 seconds remaining..." << endl;
	sleep(1);
	packetHandler->write2ByteTxOnly(portHandler, DXL_ID_2, MOVING_SPEED, 0);
	cout << "1 second remaining..." << endl;
	sleep(1);

	portHandler->closePort(); //Close USB port

	//Shuts down or reboots server (Raspberry Pi) dependent on the argument pass to this function
	if(argument == SHUTDOWN) {
		system("shutdown -P now");
	} else {
		system("shutdown -r now");
	}
}

////////////////////////////////////////////////////////////////////////////////////////////////////
// Main Function: This function gets called when the program is being executed
// @argc	How many arguments are passed to the function
// @argv	Char value of passed arguments
////////////////////////////////////////////////////////////////////////////////////////////////////
int main(int argc, char** argv) {
	//Inizializing variables and structs
	int returnValue; //Stores return values of Dynamixel functions
	int localSocket; //Local socket
	int remoteSocket; //Remote socket
	bool status = true; //Used to run while loops until status turns false
	int positionArray[2]; //Array that stores motor instructions received by client
	Mat img; //OpenCV image that will get sent to client
	struct sockaddr_in localAddr; //struct that stores network information for local socket
	struct sockaddr_in remoteAddr; //struct that stores network information for remote socket
	int addrLen = sizeof(struct sockaddr_in); //Size of sockaddr_in struct

	//Define port and protocol version for communicating with Dynamixel motors
	dynamixel::PortHandler *portHandler = dynamixel::PortHandler::getPortHandler(DEVICENAME);
	dynamixel::PacketHandler *packetHandler = dynamixel::PacketHandler::getPacketHandler(PROTOCOL_VERSION);

	//Populating struct for socket
	localAddr.sin_family = AF_INET;
	localAddr.sin_addr.s_addr = INADDR_ANY;
	localAddr.sin_port = htons(PORT);

	VideoCapture cap(VIDEOSOURCE); //Set video device

	//Setup / prepare socket and check if it an error occurs.
	if ((localSocket = socket(AF_INET , SOCK_STREAM , 0)) < 0){
		cout << "socket()\tERROR!" << endl;
		shutDownFunc(REBOOT, portHandler, packetHandler, localSocket, remoteSocket);
	}

	//Bind struct with socket and check if an error occurs.
	if (bind(localSocket,(struct sockaddr *)&localAddr , sizeof(localAddr)) < 0) {
		cout << "bind()\tERROR!" << endl;
		shutDownFunc(REBOOT, portHandler, packetHandler, localSocket, remoteSocket);
	}

	listen(localSocket , 3); // Listening for an incoming connection

	//Loop through function until a client connects to the socket
	while(status){
		if ((remoteSocket = accept(localSocket, (struct sockaddr *)&remoteAddr, (socklen_t*)&addrLen)) < 0) {
			cout << "accept()\tERROR" << endl;
			shutDownFunc(REBOOT, portHandler, packetHandler, localSocket, remoteSocket);
		} else {
			status = false;
		}
	}

	//Check if the capturing devics is up
	if (cap.isOpened() == false) {
		cout << "Opening capturing device\tERROR!" << endl;
		shutDownFunc(REBOOT, portHandler, packetHandler, localSocket, remoteSocket);
	}

	//Adjust the resolution of capture device
	cap.set(CAP_PROP_FRAME_WIDTH, RESOLUTIONWIDTH);
	cap.set(CAP_PROP_FRAME_HEIGHT, RESOLUTIONHEIGHT);

	img = Mat::zeros(RESOLUTIONHEIGHT, RESOLUTIONWIDTH, CV_8UC3); //Populate matrix with zeros

	int imgSize = img.total() * img.elemSize(); //Calucalte image size for sending over TCP_IP

	returnValue = portHandler->openPort(); //Open port for communication with Dynamixel motors

	returnValue = portHandler->setBaudRate(BAUDRATE); //Set port baudrate (Communication rate)

	//Enable torque
	returnValue = packetHandler->write1ByteTxOnly(portHandler, DXL_ID_1, TORQUE, 1);
	returnValue = packetHandler->write1ByteTxOnly(portHandler, DXL_ID_2, TORQUE, 1);
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

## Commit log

2020-01-08 Add existing file
    [jconfig.txt]
2020-01-09 Make compatible for other architectures like Arm
2020-01-10 Removed FLTK/Raspi works now
    [jconfig.txt]
2020-01-11 Added test files for TCP/IP because Raspberry Pi is too weak
    [server.cpp]
2020-01-12 Fixing Array for sending through socket
    [server.cpp]
2020-01-12 freesytle fix of two motors problem
    [server.cpp]
2020-01-13 Add files via upload
    Added shutdown or reboot option for Raspberry Pi / Added rule when tracker or receiving fails
    [client.cpp]
2020-01-13 Add files via upload
    Added support for shutdown/reboot of Raspberry PI
    [server.cpp]
2020-01-13 Corrected errors in files
    [client.cpp, server.cpp]
2020-01-13 Changed server.pp/added exepional handling/automatic reboot
    [server.cpp]
2020-01-14 Added buttons to GUI
2020-01-14 Updated client.cpp for better error handling and added some key functionalities
    [client.cpp]
2020-01-14 Updated client.cpp. Theoretically there shouldn't be any case anymore, where the Raspberry Pi won't reboot or shut down
    [client.cpp]
2020-01-23 Added 3D Files
    [PA_Drehturm.f3d]
